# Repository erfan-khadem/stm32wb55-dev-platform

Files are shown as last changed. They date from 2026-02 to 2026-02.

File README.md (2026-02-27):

# stm32wb55-dev-platform
An Evaluation and Development Platform For STM32WB55CGU6 MicroController with a few Sensors.

Note that the PCB is designed in 4 layers.

[Schematics pdf](https://github.com/erfan-khadem/stm32wb55-dev-platform/blob/main/stm32wb55-dev.pdf)

[Assembled PCB Picture](https://github.com/erfan-khadem/stm32wb55-dev-platform/blob/main/assembled.jpg?raw=true)

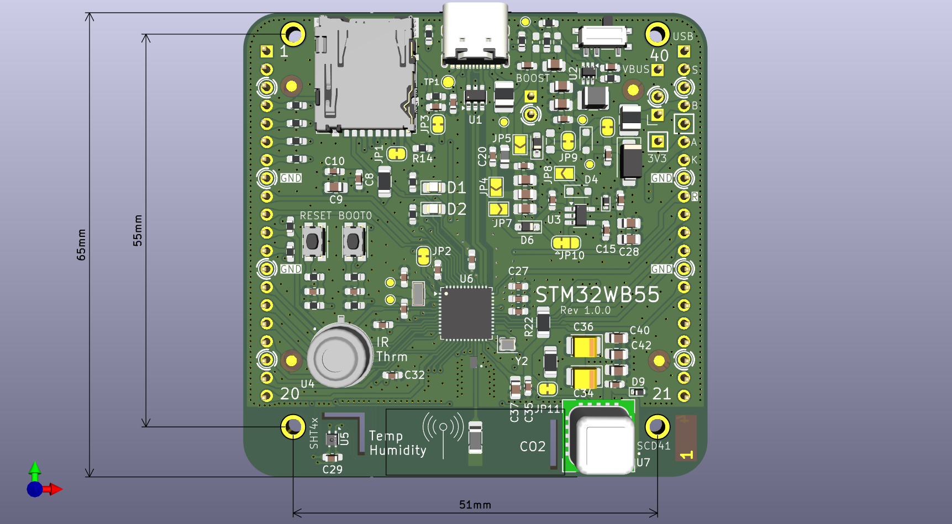
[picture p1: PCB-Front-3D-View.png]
PCB FrontSide

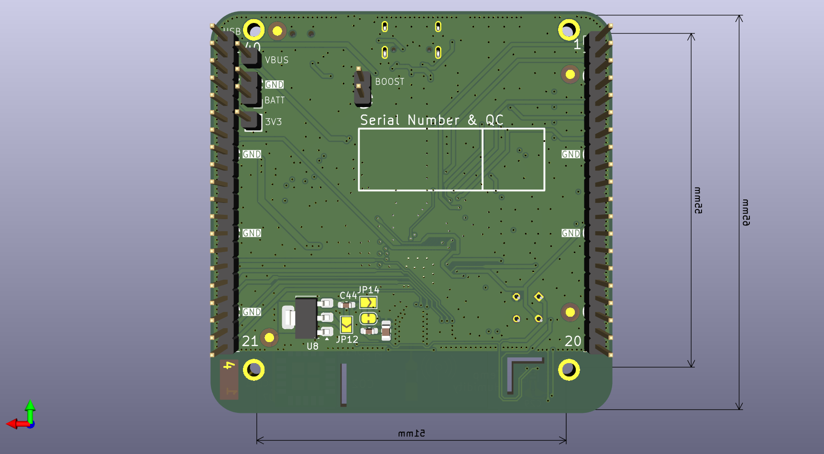
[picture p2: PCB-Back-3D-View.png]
PCB BackSide


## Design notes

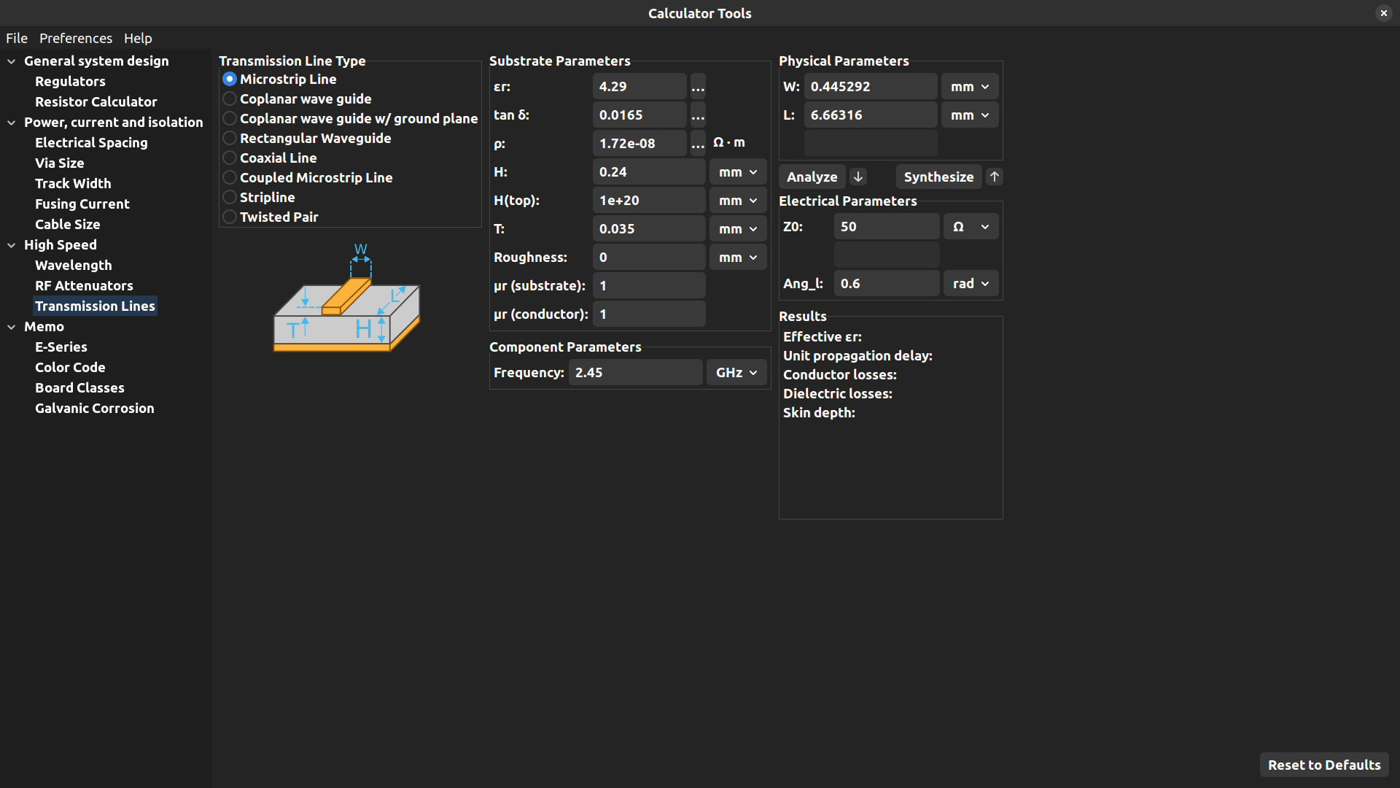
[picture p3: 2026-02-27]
stm32wb55-dev/TL-calculations/Bluetooth.png

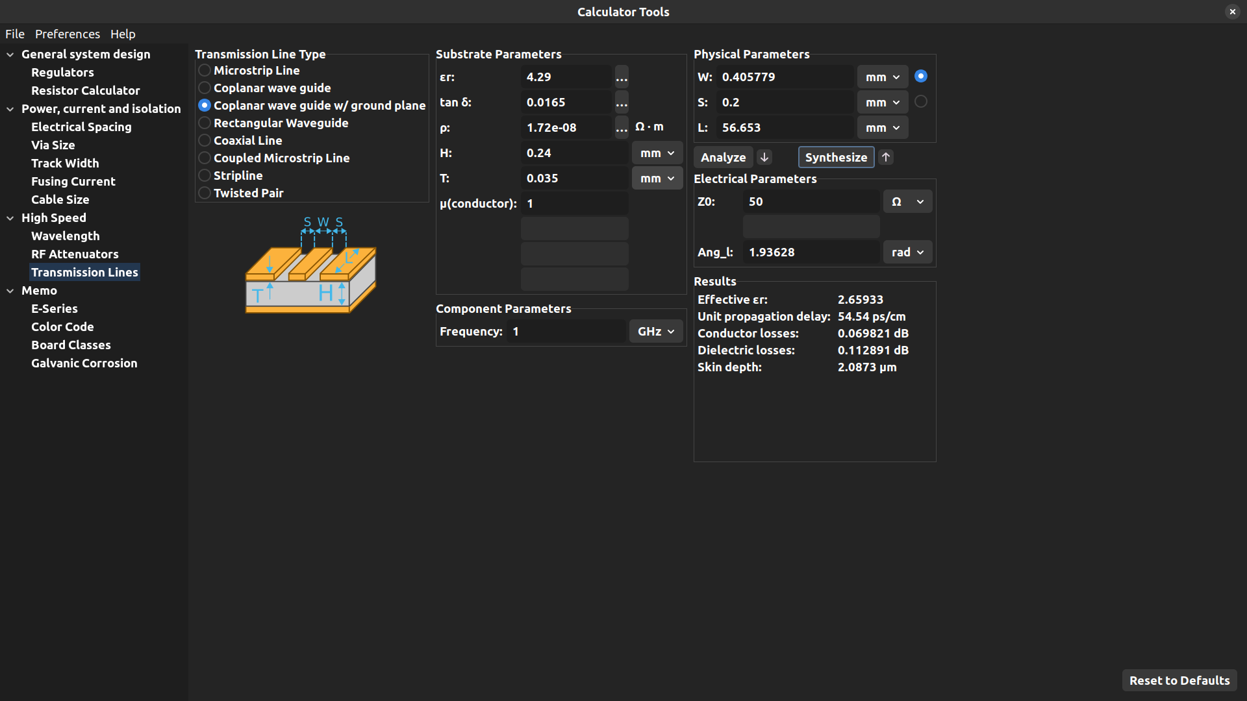
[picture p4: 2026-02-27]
stm32wb55-dev/TL-calculations/Bluetooth_Coplanar.png

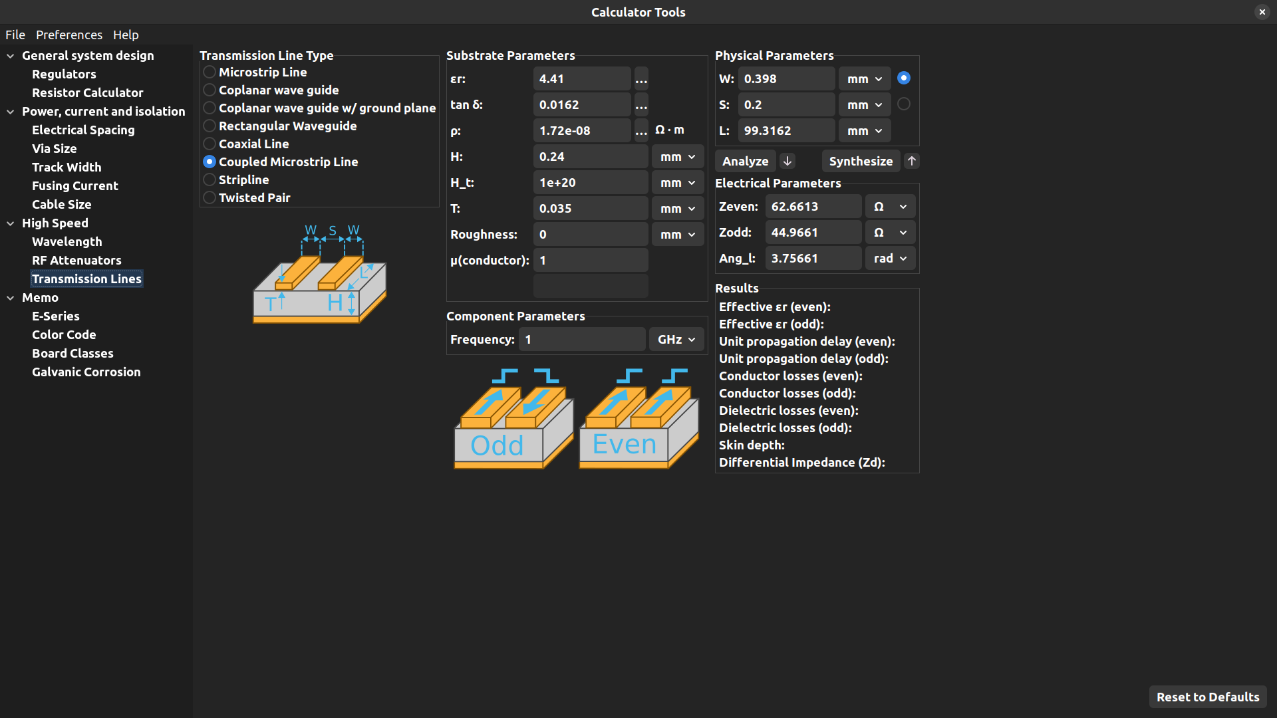
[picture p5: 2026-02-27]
stm32wb55-dev/TL-calculations/USB.png

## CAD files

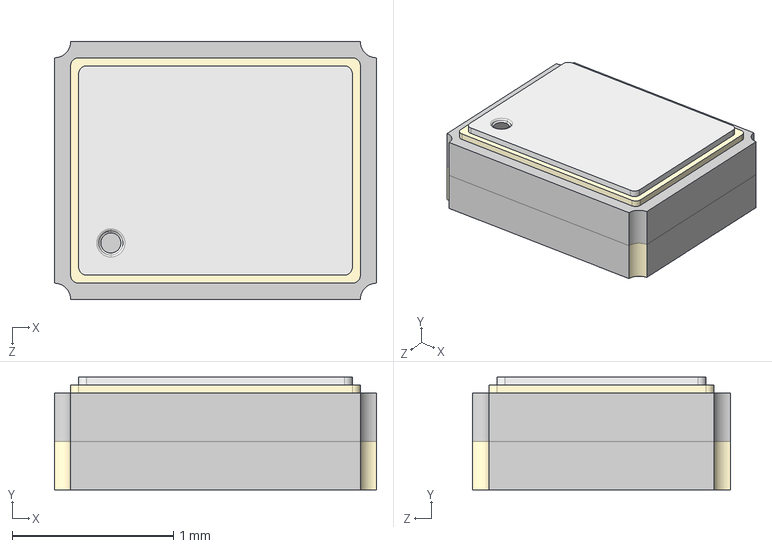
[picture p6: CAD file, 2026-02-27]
stm32wb55-dev/crystal-files/Crystal_SMD_2016-4Pin_2.0x1.6mm.step
2.00 x 0.701 x 1.60 mm

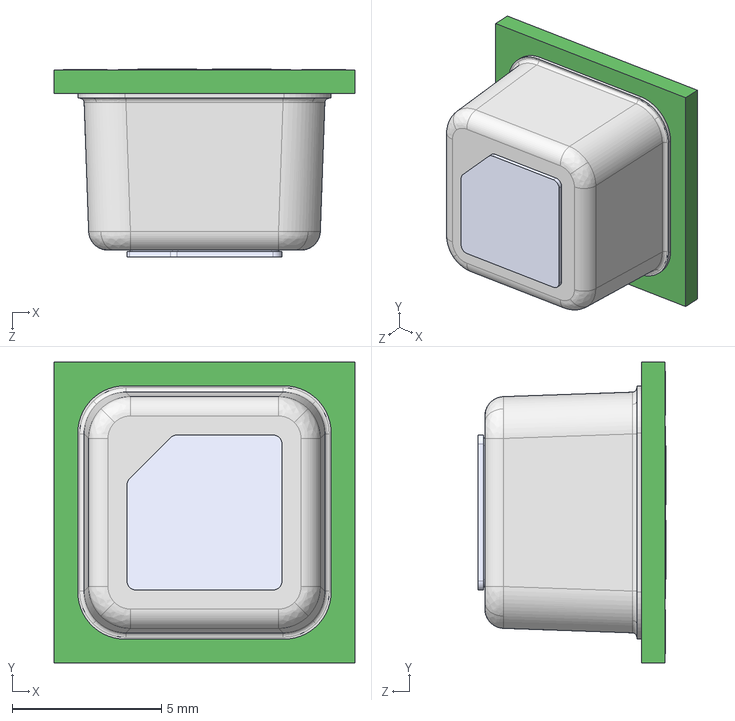
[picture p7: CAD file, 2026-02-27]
stm32wb55-dev/SCD41-D-R2/SCD41-D-R2.step
10.1 x 10.1 x 6.31 mm

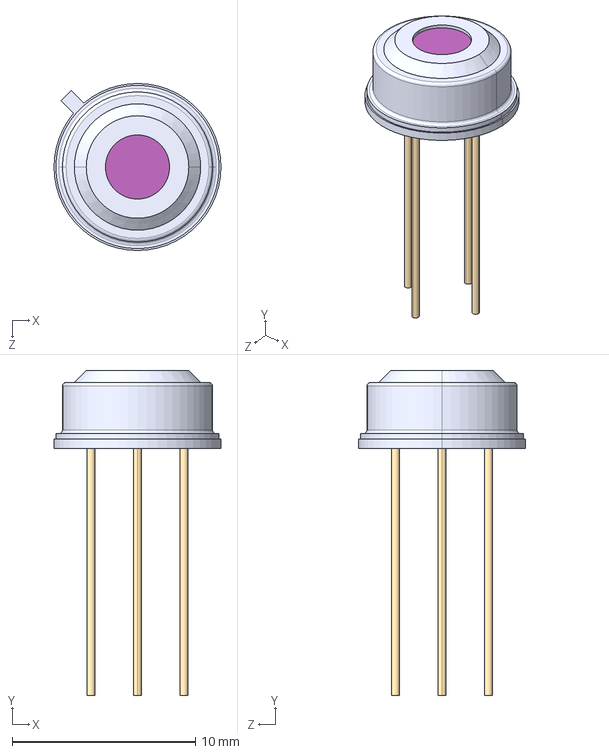
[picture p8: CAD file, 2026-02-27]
stm32wb55-dev/mlx90614/MLX90614ESF_3D_model/MLX90614ESF-BAA-000-TU.step
9.12 x 17.8 x 9.12 mm

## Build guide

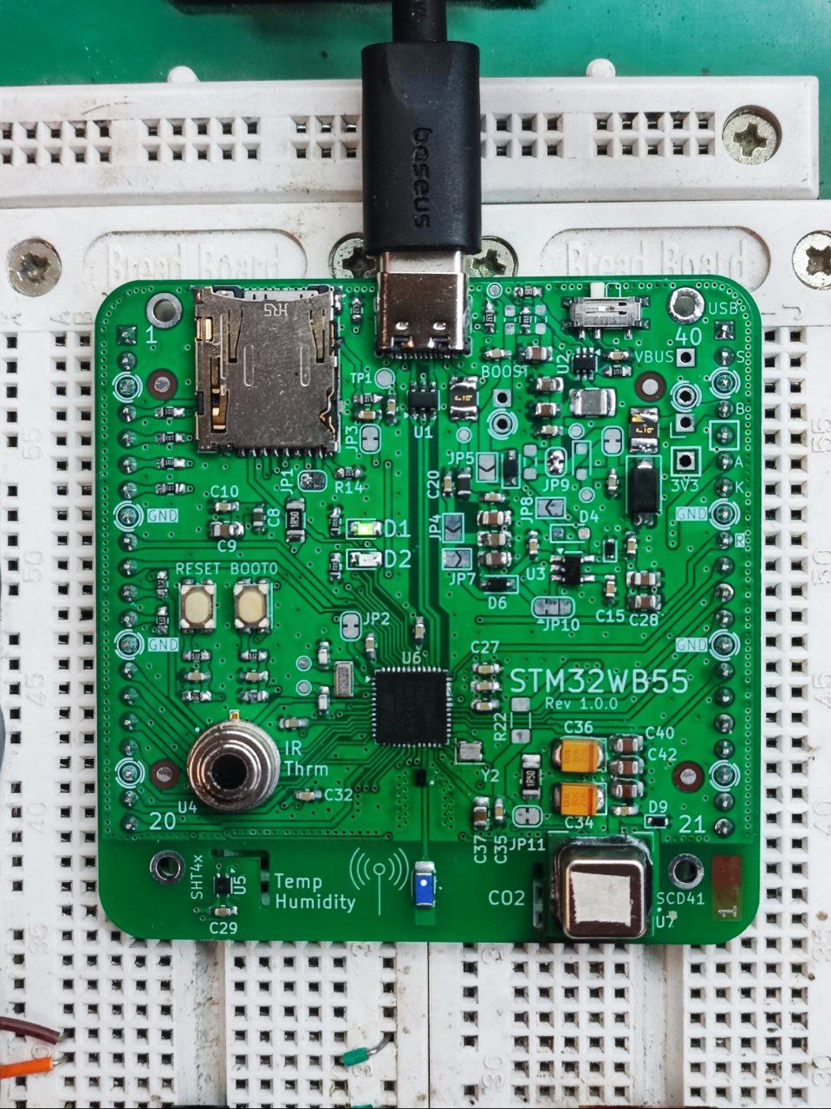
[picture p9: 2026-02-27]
assembled.jpg

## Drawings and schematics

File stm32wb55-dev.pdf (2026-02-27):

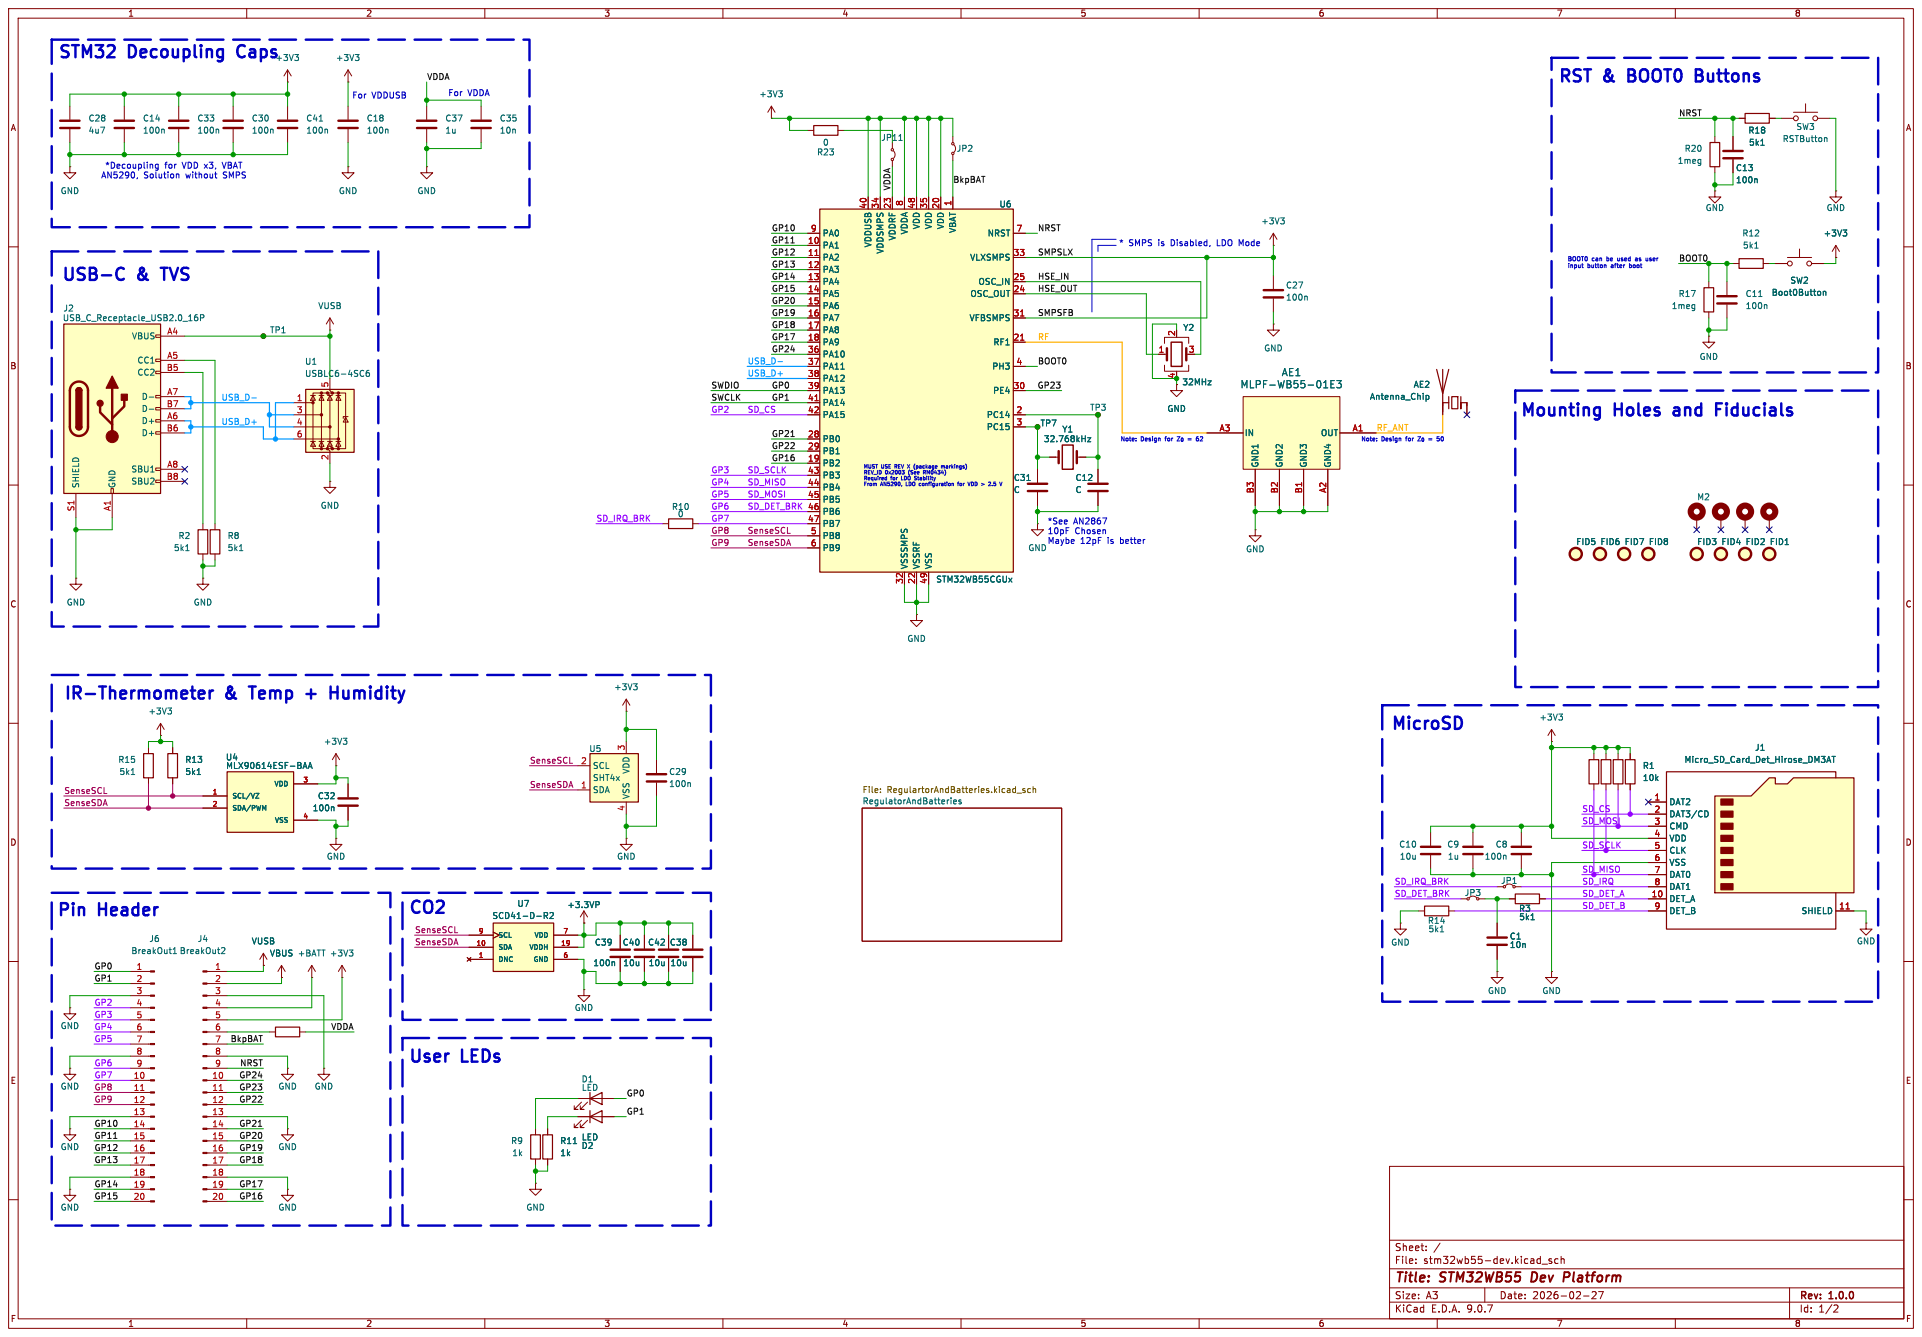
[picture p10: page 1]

NRST 7 VLXSMPS 33 OSC_IN 25 OSC_OUT 24 VFBSMPS 31 RF1 21 PH3 4 PE4 30 PC14 2 PC15 3 VBAT

8 VSSSMPS 32 VDDRF 23 VDDSMPS 34 VDDUSB 40 PA0 9 PA1 10 PA2 11 PA3 12 PA4 13 PA5 14 PA6 15 PA7 16 PA8 17 PA9 18 PA10 36 PA11 37 PA12 38 PA13 39 PA14 41 PA15 42 PB0 28 PB1 29 PB2 19 PB3 43 PB4 44 PB5 45 PB6 46 PB7 47 PB8 5 PB9 6 U6 STM32WB55CGUx GP6 GP7 GP5 GP8 SD_MOSI HSE_IN

8 VSSSMPS 32 VDDRF 23 VDDSMPS 34 VDDUSB 40 PA0 9 PA1 10 PA2 11 PA3 12 PA4 13 PA5 14 PA6 15 PA7 16 PA8 17 PA9 18 PA10 36 PA11 37 PA12 38 PA13 39 PA14 41 PA15 42 PB0 28 PB1 29 PB2 19 PB3 43 PB4 44 PB5 45 PB6 46 PB7 47 PB8 5 PB9 6 TP7 C31 C

1 VDD 20 VDD 35 VSS 49 VDD 48 VSSRF 22 VDDA

3 U6 STM32WB55CGUx NRST 7 VLXSMPS 33 OSC_IN 25 OSC_OUT 24 VFBSMPS 31 RF1 21 PH3 4 PE4 30 PC14 2 PC15 3 VBAT

BOOT0 can be used as user

Mounting Holes and Fiducials

RegulatorAndBatteries File: RegulartorAndBatteries.kicad_sch GND

File: stm32wb55-dev.kicad_sch Sheet: /
Id: 1/2 Title: STM32WB55 Dev Platform

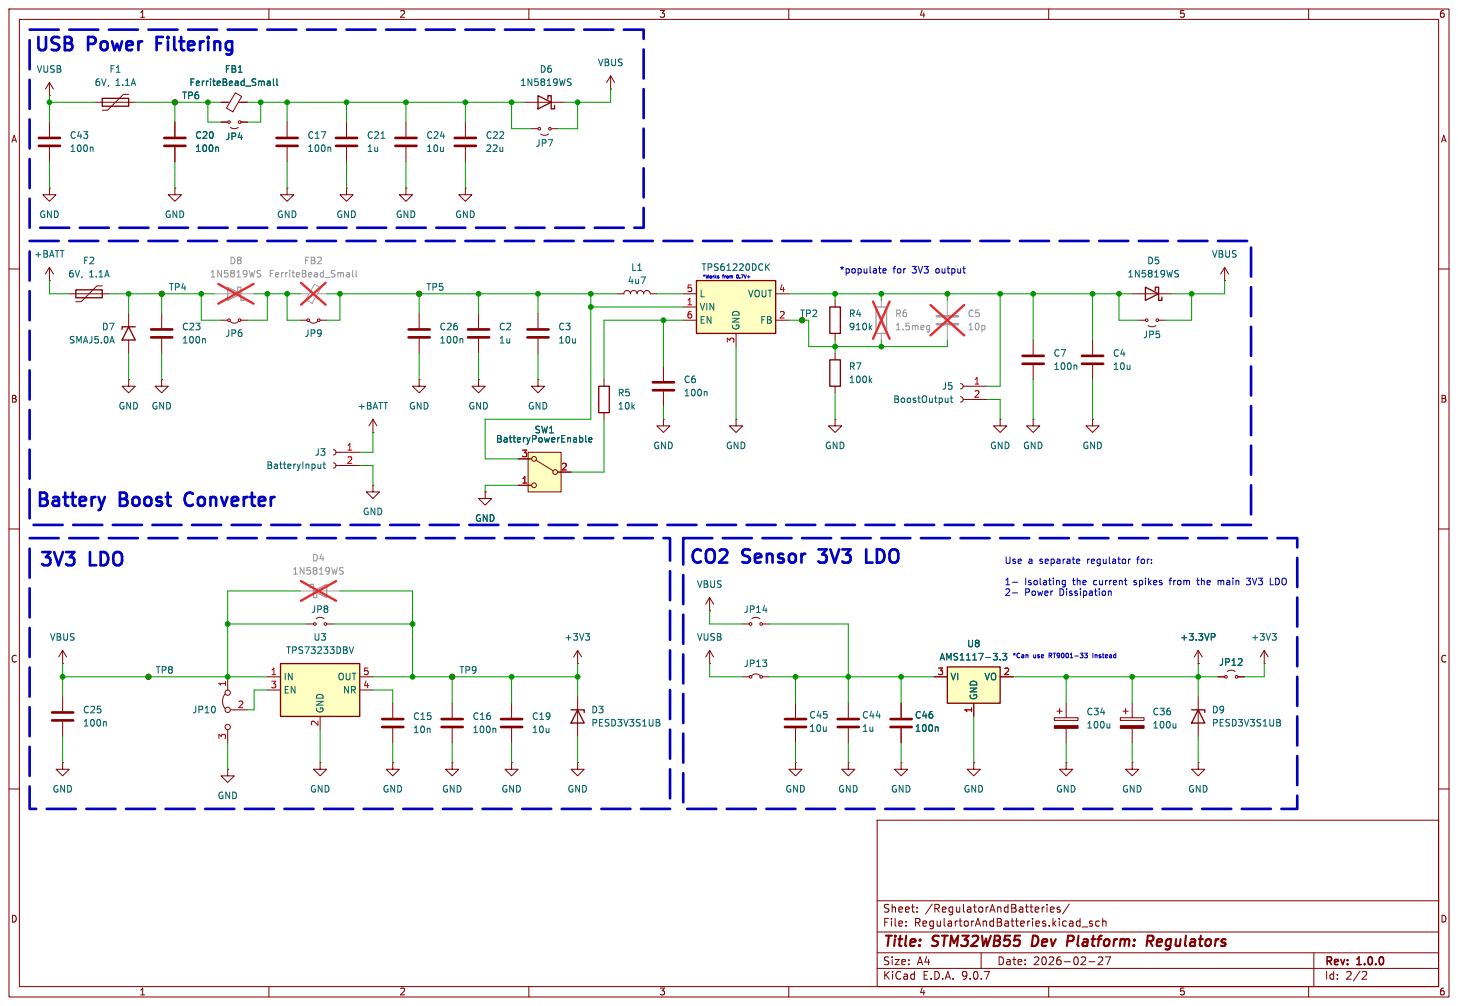
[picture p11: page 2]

File: RegulartorAndBatteries.kicad_sch Sheet: /RegulatorAndBatteries/ GND

Id: 2/2 Title: STM32WB55 Dev Platform: Regulators

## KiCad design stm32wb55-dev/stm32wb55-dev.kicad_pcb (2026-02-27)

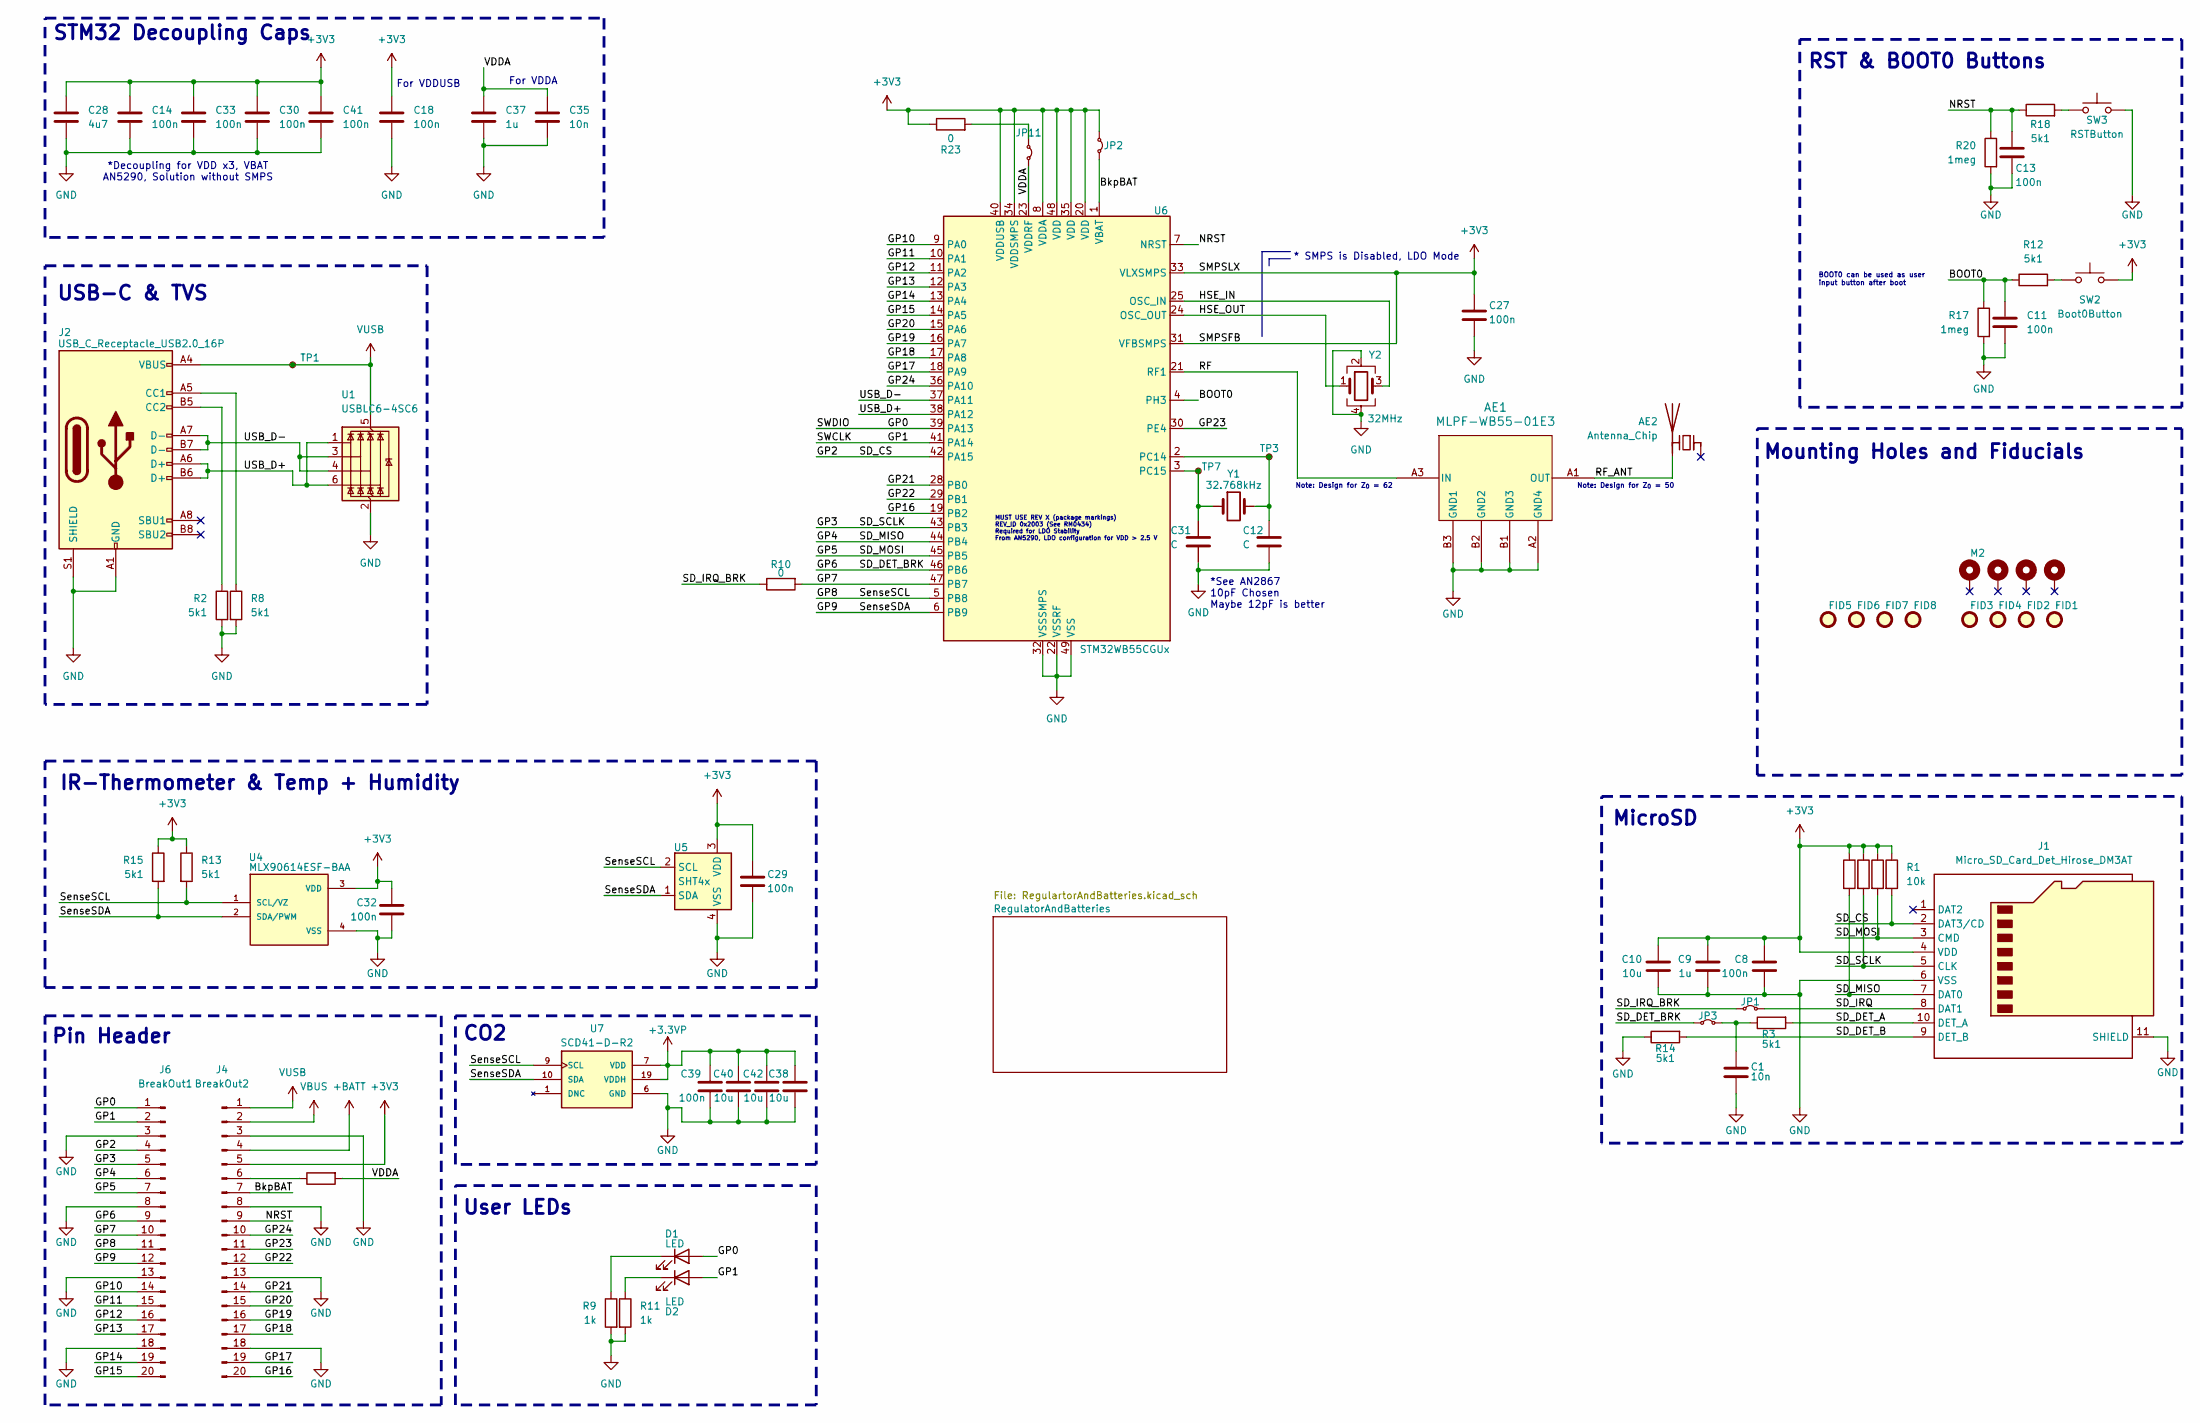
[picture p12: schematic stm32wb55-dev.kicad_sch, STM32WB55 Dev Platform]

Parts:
AE1: MLPF-WB55-01E3; MLPF-WB55-01E3_STM-M
AE2: Antenna_Chip; L_1206_3216Metric_Pad1.22x1.90mm_HandSolder
C1, C35: 10n; C_0603_1608Metric_Pad1.08x0.95mm_HandSolder
C8, C11, C13, C14, C18, C27, C29, C30, C32, C33, C39, C41: 100n; C_0603_1608Metric_Pad1.08x0.95mm_HandSolder
C9, C37: 1u; C_0805_2012Metric_Pad1.18x1.45mm_HandSolder
C10: 10u; C_0603_1608Metric_Pad1.08x0.95mm_HandSolder
C12, C31: C; C_0603_1608Metric_Pad1.08x0.95mm_HandSolder
C28: 4u7; C_0805_2012Metric_Pad1.18x1.45mm_HandSolder
C38, C40, C42: 10u; C_0805_2012Metric_Pad1.18x1.45mm_HandSolder
D1, D2: LED; LED_0805_2012Metric_Pad1.15x1.40mm_HandSolder
FID1, FID2, FID3, FID4, FID5, FID6, FID7, FID8: Fiducial; Fiducial_1.5mm_Mask3mm
H1, H2, H3, H4: M2; MountingHole_2.2mm_M2_ISO7380_Pad_TopBottom
J1: Micro_SD_Card_Det_Hirose_DM3AT; microSD_HC_Hirose_DM3AT-SF-PEJM5
J2: USB_C_Receptacle_USB2.0_16P; USB_C_Receptacle_GCT_USB4105-xx-A_16P_TopMnt_Horizontal
J4: BreakOut2; PinHeader_1x20_P2.54mm_Vertical
J6: BreakOut1; PinHeader_1x20_P2.54mm_Vertical
JP1: SD_IRQ_BREAKER; SolderJumper-2_P1.3mm_Bridged_RoundedPad1.0x1.5mm
JP2: VBATBreaker; SolderJumper-2_P1.3mm_Bridged_RoundedPad1.0x1.5mm
JP3: SD_DET_BREAKER; SolderJumper-2_P1.3mm_Bridged_RoundedPad1.0x1.5mm
JP11: VDDABreaker; SolderJumper-2_P1.3mm_Bridged_RoundedPad1.0x1.5mm
R1, R16, R19, R21: 10k; R_0603_1608Metric_Pad0.98x0.95mm_HandSolder
R2, R3, R8, R12, R13, R14, R15, R18: 5k1; R_0603_1608Metric_Pad0.98x0.95mm_HandSolder
R9, R11: 1k; R_0603_1608Metric_Pad0.98x0.95mm_HandSolder
R10, R22, R23: 0; R_1206_3216Metric_Pad1.30x1.75mm_HandSolder
R17, R20: 1meg; R_0603_1608Metric_Pad0.98x0.95mm_HandSolder
SW2: Boot0Button; SW_Push_1P1T_NO_Vertical_Wuerth_434133025816
SW3: RSTButton; SW_Push_1P1T_NO_Vertical_Wuerth_434133025816
TP1: USBPowerConnMonitor; TestPoint_Pad_D1.5mm
TP3: LSEMon2; TestPoint_Pad_D1.0mm
TP7: LSEMon1; TestPoint_Pad_D1.0mm
U1: USBLC6-4SC6; SOT-23-6
U4: MLX90614ESF-BAA; TO254P942H425-4; PARTREV 13
U5: SHT4x; Sensirion_DFN-4_1.5x1.5mm_P0.8mm_SHT4x_NoCentralPad
U6: STM32WB55CGUx; QFN-48-1EP_7x7mm_P0.5mm_EP5.6x5.6mm
U7: SCD41-D-R2; XDCR_SCD41-D-R2; PARTREV 1.2; DigiKey_Part_Number 1649-SCD41-D-R2CT-ND
Y1: 32.768kHz; Crystal_SMD_3215-2Pin_3.2x1.5mm
Y2: 32MHz; Crystal_SMD_2016-4Pin_2.0x1.6mm

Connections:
+3.3VP: C38.1, C39.1, C40.1, C42.1, U7.7 (VDD), U7.19 (VDDH); also elsewhere on the board
+3V3: C8.1, C9.1, C10.1, C14.1, C18.1, C27.1, C28.1, C29.1, C30.1, C32.1, C33.1, C41.1, J1.4 (VDD), J4.5, JP2.1 (A), R1.1, R13.1, R15.1, R16.1, R19.1, R21.1, R23.1, SW2.2, U4.3 (VDD), U5.3 (VDD), U6.8 (VDDA), U6.20 (VDD), U6.31 (VFBSMPS), U6.33 (VLXSMPS), U6.34 (VDDSMPS), U6.35 (VDD), U6.40 (VDDUSB), U6.48 (VDD); also elsewhere on the board
+BATT: J4.4; also elsewhere on the board
/BOOT0: C11.1, R12.1, R17.1, U6.4 (PH3)
/BkpBAT: J4.7, JP2.2 (B), U6.1 (VBAT)
/GP0: D1.2 (A), J6.1, U6.39 (PA13)
/GP1: D2.2 (A), J6.2, U6.41 (PA14)
/GP2: J1.2 (DAT3/CD), J6.4, R1.2, U6.42 (PA15)
/GP3: J1.5 (CLK), J6.5, R19.2, U6.43 (PB3)
/GP4: J1.7 (DAT0), J6.6, R21.2, U6.44 (PB4)
/GP5: J1.3 (CMD), J6.7, R16.2, U6.45 (PB5)
/GP6: J6.9, JP3.1 (A), U6.46 (PB6)
/GP7: J6.10, R10.2, U6.47 (PB7)
/GP8: J6.11, R13.2, U4.1 (SCL/VZ), U5.2 (SCL), U6.5 (PB8), U7.9 (SCL)
/GP9: J6.12, R15.2, U4.2 (SDA/PWM), U5.1 (SDA), U6.6 (PB9), U7.10 (SDA)
/GP10: J6.14, U6.9 (PA0)
/GP11: J6.15, U6.10 (PA1)
/GP12: J6.16, U6.11 (PA2)
/GP13: J6.17, U6.12 (PA3)
/GP14: J6.19, U6.13 (PA4)
/GP15: J6.20, U6.14 (PA5)
/GP16: J4.20, U6.19 (PB2)
/GP17: J4.19, U6.18 (PA9)
/GP18: J4.17, U6.17 (PA8)
/GP19: J4.16, U6.16 (PA7)
/GP20: J4.15, U6.15 (PA6)
/GP21: J4.14, U6.28 (PB0)
/GP22: J4.12, U6.29 (PB1)
/GP23: J4.11, U6.30 (PE4)
/GP24: J4.10, U6.36 (PA10)
/HSE_IN: U6.25 (OSC_IN), Y2.3
/HSE_OUT: U6.24 (OSC_OUT), Y2.1
/NRST: C13.1, J4.9, R18.1, R20.1, U6.7 (NRST)
/RF: AE1.A3 (IN), U6.21 (RF1)
/RF_ANT: AE1.A1 (OUT), AE2.2 (PCB_Trace)
/SD_DET_A: J1.10 (DET_A), R3.2
/SD_DET_B: J1.9 (DET_B), R14.2
/SD_IRQ: J1.8 (DAT1), JP1.2 (B)
/SD_IRQ_BRK: JP1.1 (A), R10.1
/USB_D+: J2.A6 (D+), J2.B6 (D+), U1.1 (I/O1), U1.6 (I/O4), U6.38 (PA12)
/USB_D-: J2.A7 (D-), J2.B7 (D-), U1.3 (I/O2), U1.4 (I/O3), U6.37 (PA11)
/VDDA: C35.1, C37.1, JP11.2 (B), R22.2, U6.23 (VDDRF)
GND: AE1.A2 (GND4), AE1.B1 (GND3), AE1.B2 (GND2), AE1.B3 (GND1), C1.2, C8.2, C9.2, C10.2, C11.2, C12.2, C13.2, C14.2, C18.2, C27.2, C28.2, C29.2, C30.2, C31.2, C32.2, C33.2, C35.2, C37.2, C38.2, C39.2, C40.2, C41.2, C42.2, J1.6 (VSS), J1.11 (SHIELD), J2.A1 (GND), J2.A12 (GND), J2.B1 (GND), J2.B12 (GND), J2.S1 (SHIELD), J4.3, J4.8, J4.13, J4.18, J6.3, J6.8, J6.13, J6.18, R2.2, R8.2, R9.2, R11.2, R14.1, R17.2, R20.2, SW3.2, U1.2 (GND), U4.4 (VSS), U5.4 (VSS), U6.22 (VSSRF), U6.32 (VSSSMPS), U6.49 (VSS), U7.6 (GND), U7.20 (GND), U7.21 (GND), Y2.2, Y2.4; also elsewhere on the board
unnamed: D1.1 (K), R9.1
unnamed: D2.1 (K), R11.1
unnamed: J2.A5 (CC1), R8.1
unnamed: J2.B5 (CC2), R2.1
unnamed: J4.6, R22.1
unnamed: C1.1, JP3.2 (B), R3.1
unnamed: JP11.1 (A), R23.2
unnamed: R12.2, SW2.1
unnamed: R18.2, SW3.1
unnamed: C12.1, TP3.1, U6.2 (PC14), Y1.2
unnamed: C31.1, TP7.1, U6.3 (PC15), Y1.1
VBUS: J4.2; also elsewhere on the board
VUSB: J2.A4 (VBUS), J2.A9 (VBUS), J2.B4 (VBUS), J2.B9 (VBUS), J4.1, TP1.1, U1.5 (VBUS); also elsewhere on the board

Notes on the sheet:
Note: Design for Z_{0} = 50
Pin Header
Mounting Holes and Fiducials
Note: Design for Z_{0} = 62
*Decoupling for VDD x3, VBAT AN5290, Solution without SMPS
BOOT0 can be used as user input button after boot
RST & BOOT0 Buttons
USB-C & TVS
For VDDA
IR-Thermometer & Temp + Humidity
User LEDs
* SMPS is Disabled, LDO Mode
MicroSD
CO2
*See AN2867 10pF Chosen Maybe 12pF is better
MUST USE REV X (package markings) REV_ID 0x2003 (See RM0434) Required for LDO Stability From AN5290, LDO configuration for VDD > 2.5 V
STM32 Decoupling Caps
For VDDUSB

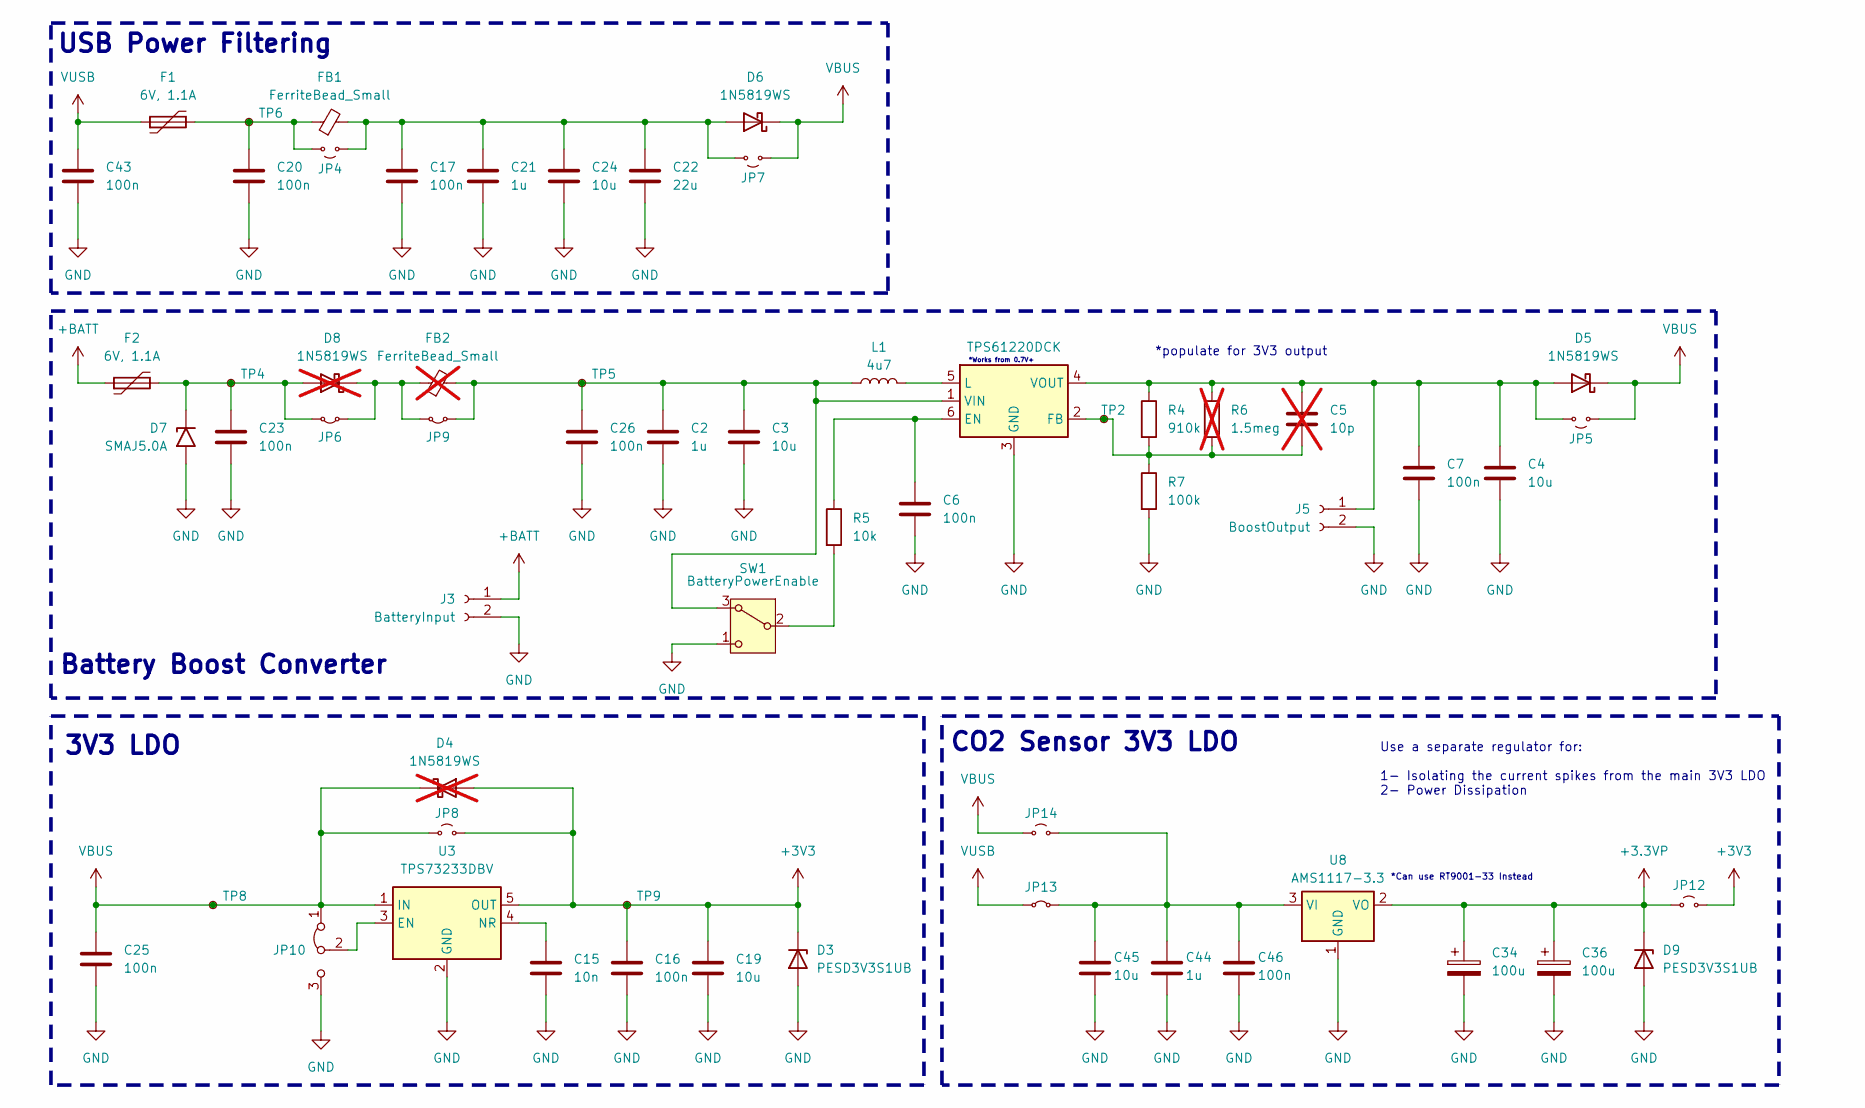
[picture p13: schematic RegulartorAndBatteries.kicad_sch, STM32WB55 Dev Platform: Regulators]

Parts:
C2, C21: 1u; C_0805_2012Metric_Pad1.18x1.45mm_HandSolder
C3, C4, C19, C24, C45: 10u; C_0805_2012Metric_Pad1.18x1.45mm_HandSolder
C5: 10p; C_0603_1608Metric_Pad1.08x0.95mm_HandSolder; not fitted
C6, C7, C16, C17, C20, C23, C25, C26, C43, C46: 100n; C_0603_1608Metric_Pad1.08x0.95mm_HandSolder
C15: 10n; C_0603_1608Metric_Pad1.08x0.95mm_HandSolder
C22: 22u; C_0805_2012Metric_Pad1.18x1.45mm_HandSolder
C34, C36: 100u; CP_EIA-3528-21_Kemet-B_HandSolder
C44: 1u; C_0603_1608Metric_Pad1.08x0.95mm_HandSolder
D3, D9: PESD3V3S1UB; D_SOD-523
D4, D8: 1N5819WS; D_SOD-323_HandSoldering; not fitted
D5, D6: 1N5819WS; D_SOD-323_HandSoldering
D7: SMAJ5.0A; D_SMA
F1, F2: 6V, 1.1A; Fuse_1210_3225Metric_Pad1.42x2.65mm_HandSolder
FB1: FerriteBead_Small; L_0805_2012Metric_Pad1.05x1.20mm_HandSolder
FB2: FerriteBead_Small; L_0805_2012Metric_Pad1.05x1.20mm_HandSolder; not fitted
J3: BatteryInput; PinHeader_1x02_P2.54mm_Vertical
J5: BoostOutput; PinHeader_1x02_P2.54mm_Vertical
JP4: BypassVUSBFerriteBead; SolderJumper-2_P1.3mm_Open_TrianglePad1.0x1.5mm
JP5, JP12, JP14: BypassBoostDiode; SolderJumper-2_P1.3mm_Open_TrianglePad1.0x1.5mm
JP6, JP13: BatteryDiodeBypass; SolderJumper-2_P1.3mm_Bridged_RoundedPad1.0x1.5mm
JP7: BypassVUSBDiode; SolderJumper-2_P1.3mm_Open_TrianglePad1.0x1.5mm
JP8: BypassLDO; SolderJumper-2_P1.3mm_Open_TrianglePad1.0x1.5mm
JP9: BypassBatteryFerriteBead; SolderJumper-2_P1.3mm_Bridged_RoundedPad1.0x1.5mm
JP10: LDODisable; SolderJumper-3_P1.3mm_Bridged12_RoundedPad1.0x1.5mm
L1: 4u7; L_1210_3225Metric_Pad1.42x2.65mm_HandSolder
R4: 910k; R_0603_1608Metric_Pad0.98x0.95mm_HandSolder
R5: 10k; R_0603_1608Metric_Pad0.98x0.95mm_HandSolder
R6: 1.5meg; R_0603_1608Metric_Pad0.98x0.95mm_HandSolder; not fitted
R7: 100k; R_0603_1608Metric_Pad0.98x0.95mm_HandSolder
SW1: BatteryPowerEnable; SW_SPDT_PCM12
TP2: BoostFBMon; TestPoint_Pad_D1.0mm
TP4: BattInAlt; TestPoint_Pad_D1.0mm
TP5: BoostVinMon; TestPoint_Pad_D1.0mm
TP6: VUSBProtMon; TestPoint_Pad_D1.0mm
TP8: LDOVinMon; PinHeader_1x01_P2.54mm_Vertical
TP9: LDOOutMon; PinHeader_1x01_P2.54mm_Vertical
U2: TPS61220DCK; Texas_R-PDSO-G6
U3: TPS73233DBV; SOT-23-5_HandSoldering
U8: AMS1117-3.3; SOT-223-3_TabPin2

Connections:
+3.3VP: C34.1, C36.1, D9.1 (K), JP12.2 (B), U8.2 (VO); also elsewhere on the board
+3V3: C16.1, C19.1, D3.1 (K), D4.2 (A), JP8.1 (A), JP12.1 (A), TP9.1, U3.5 (OUT); also elsewhere on the board
+BATT: F2.1, J3.1; also elsewhere on the board
GND: C2.2, C3.2, C4.2, C6.2, C7.2, C15.2, C16.2, C17.2, C19.2, C20.2, C21.2, C22.2, C23.2, C24.2, C25.2, C26.2, C34.2, C36.2, C43.2, C44.2, C45.2, C46.2, D3.2 (A), D7.2 (A2), D9.2 (A), J3.2, J5.2, JP10.3 (B), R7.2, SW1.1 (C), U2.3 (GND), U3.2 (GND), U8.1 (GND); also elsewhere on the board
unnamed: C4.1, C5.1, C7.1, D5.2 (A), J5.1, JP5.1 (A), R4.1, R6.1, U2.4 (VOUT)
unnamed: C17.1, C21.1, C22.1, C24.1, D6.2 (A), FB1.2, JP4.2 (B), JP7.1 (A)
unnamed: C23.1, D7.1 (A1), D8.2 (A), F2.2, JP6.1 (A), TP4.1
unnamed: D8.1 (K), FB2.1, JP6.2 (B), JP9.1 (A)
unnamed: C20.1, F1.2, FB1.1, JP4.1 (A), TP6.1
unnamed: C2.1, C3.1, C26.1, FB2.2, JP9.2 (B), L1.1, SW1.3 (A), TP5.1, U2.1 (VIN)
unnamed: JP10.2 (C), U3.3 (EN)
unnamed: C44.1, C45.1, C46.1, JP13.1 (A), JP14.1 (A), U8.3 (VI)
unnamed: R5.2, SW1.2 (B)
unnamed: C6.1, R5.1, U2.6 (EN)
unnamed: C5.2, R4.2, R6.2, R7.1, TP2.1, U2.2 (FB)
unnamed: L1.2, U2.5 (L)
unnamed: C15.1, U3.4 (NR)
VBUS: C25.1, D4.1 (K), D5.1 (K), D6.1 (K), JP5.2 (B), JP7.2 (B), JP8.2 (B), JP10.1 (A), JP14.2 (B), TP8.1, U3.1 (IN); also elsewhere on the board
VUSB: C43.1, F1.1, JP13.2 (B); also elsewhere on the board

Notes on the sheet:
Battery Boost Converter
*populate for 3V3 output
CO2 Sensor 3V3 LDO
3V3 LDO
USB Power Filtering
Use a separate regulator for: 1- Isolating the current spikes from the main 3V3 LDO 2- Power Dissipation
*Works from 0.7V+
*Can use RT9001-33 Instead

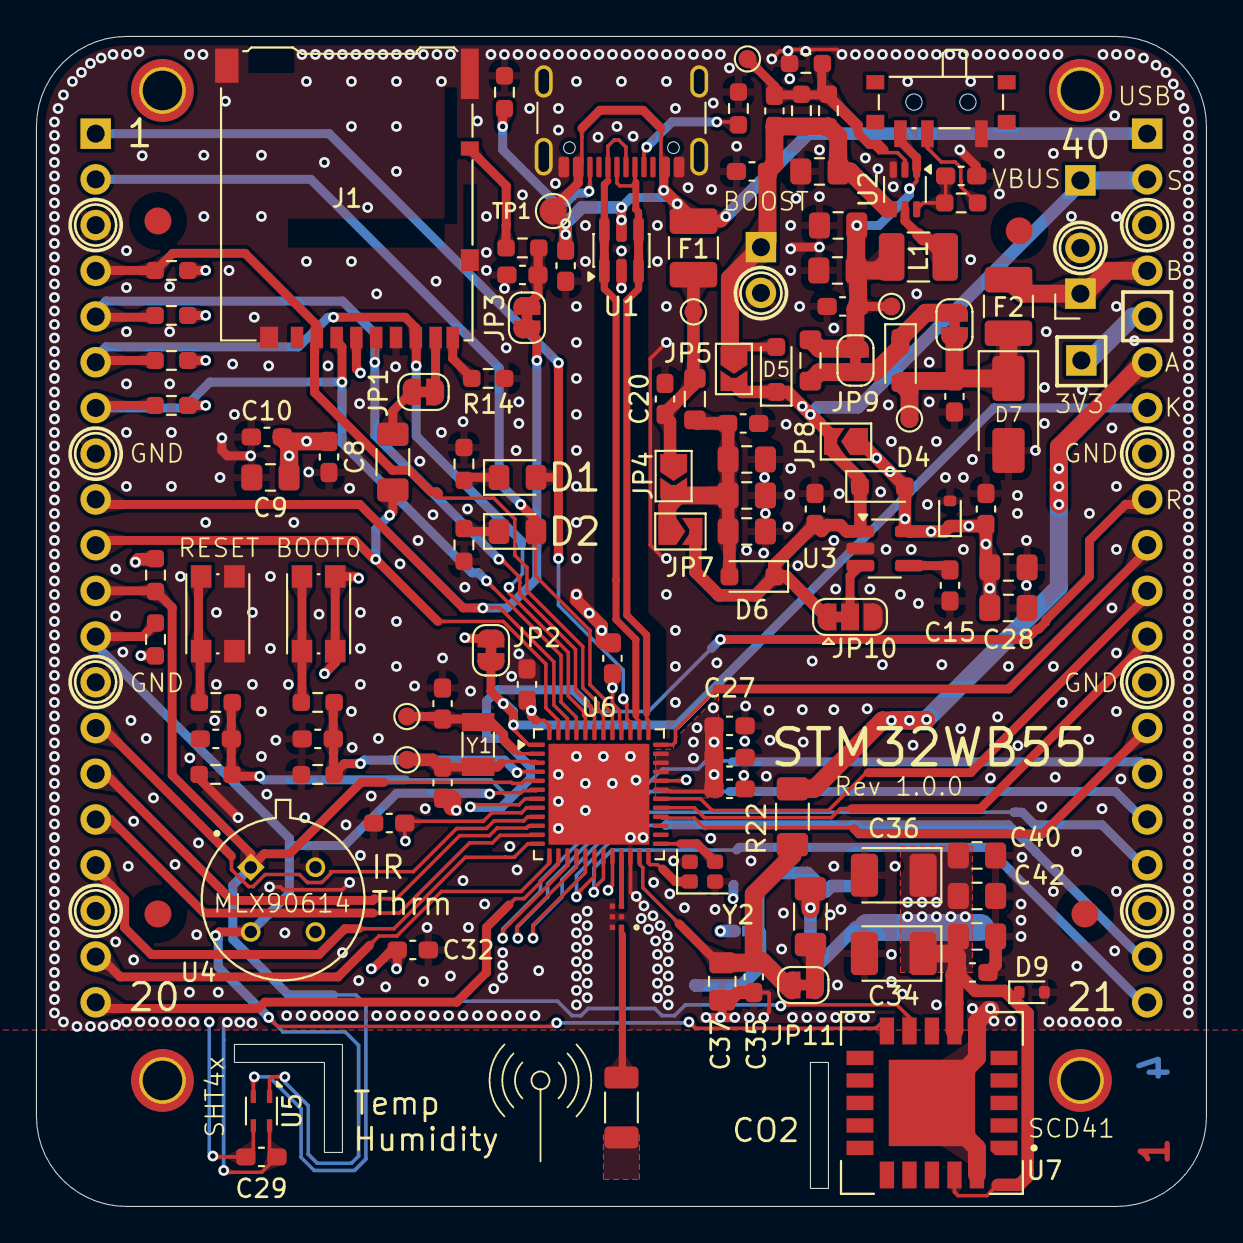
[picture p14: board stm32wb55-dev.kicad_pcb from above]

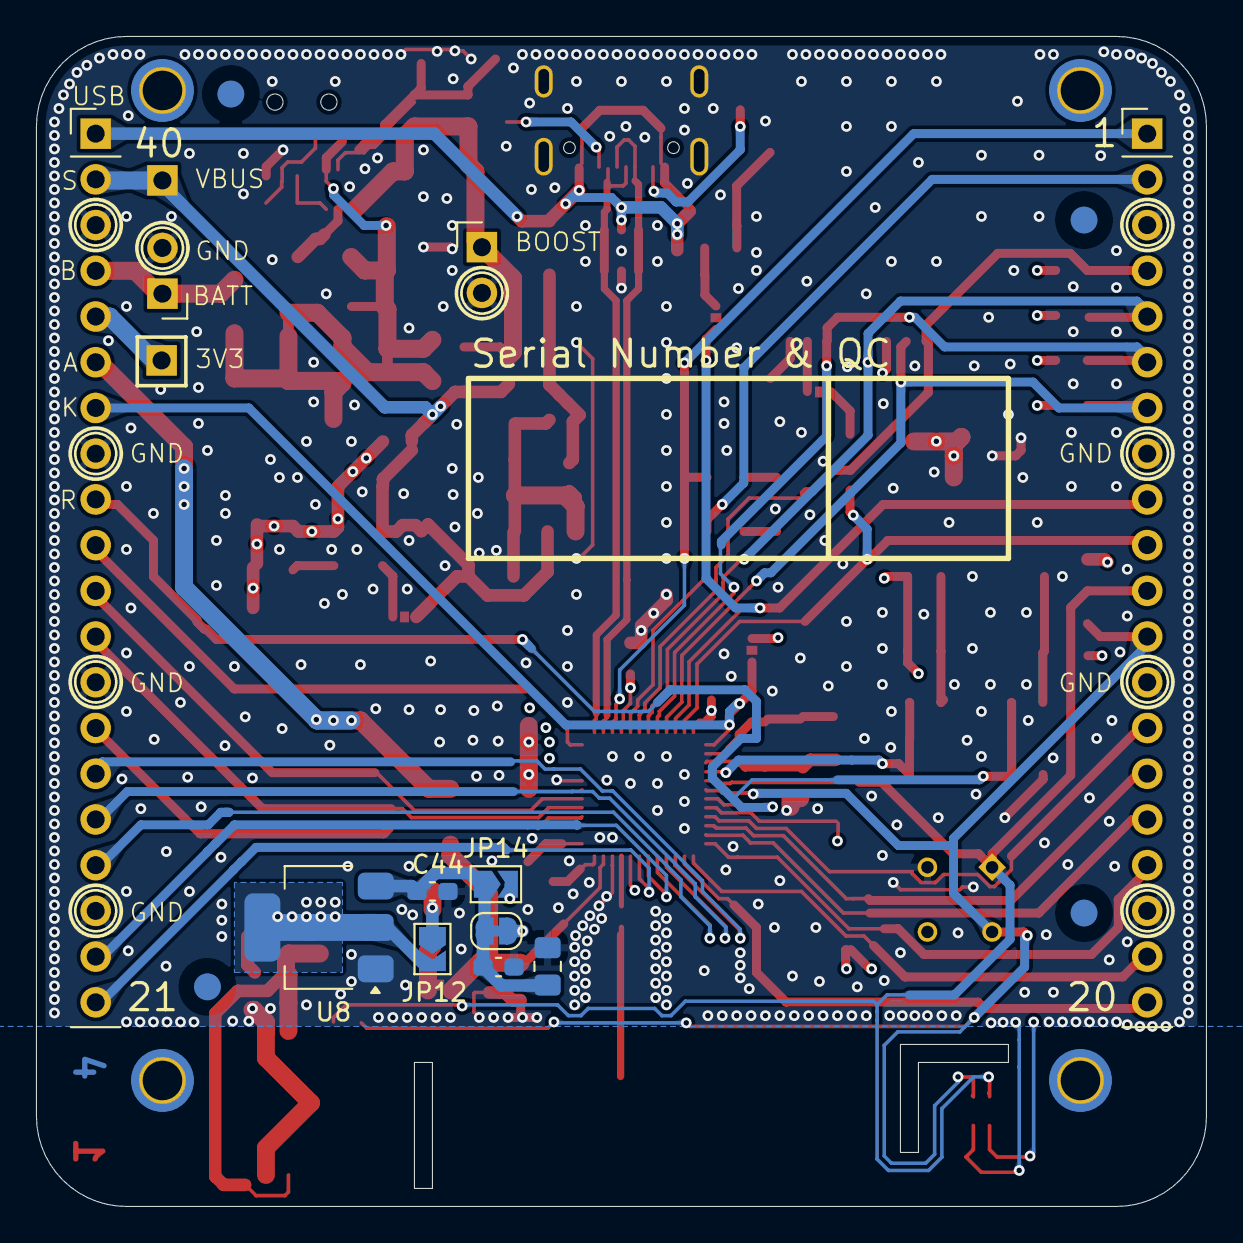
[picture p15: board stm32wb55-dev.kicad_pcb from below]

Board: 4 copper layers, 65.0 x 65.0 mm, 139 parts (17 on the bottom side), 69 nets.
